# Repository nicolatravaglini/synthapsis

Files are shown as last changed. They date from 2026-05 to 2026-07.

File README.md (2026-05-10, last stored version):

# Synthapsis

## Introduzione

Synthapsis e' un sintetizzatore portatile progettato con l'intento di estrarre melodie dal chaos.
Genera note casuali seguendo un ordine stocastico definito da una matrice di Markov, modificabile in
tempo reale mediante connessioni fisiche tra pin.

## Funzionalita'

Il dispositivo è costituito da un'interfaccia a 24 nodi metallici (12 input e 12 output) tramite
i quali l'utente, utilizzando cavi con clip a coccodrillo, modella dinamicamente una catena di Markov.
Questa struttura definisce le probabilità di transizione tra le dodici note della scala cromatica:
la probabilità di passare dalla nota corrente a una delle note successive è distribuita uniformemente
tra tutti i nodi di destinazione fisicamente collegati al pin di partenza.

Per la selezione della nota successiva, al fine di evitare i pattern prevedibili tipici dei generatori
di numeri pseudo-casuali (PRNG), il software impiega un True Random Number Generator (TRNG) che sfrutta
l'hardware dell'ESP32 per estrarre entropia basata sul rumore di clock.

Dei LED disposti sotto ciascuno pin supportano la user-experience, indicando in tempo reale la nota
attualmente riprodotta mediante la loro accensione.

Le idee sulla disposizione dei pin, e conseguentemente dei LED, e' ancora da definirsi bene. Tuttavia
quella che a mio avviso sembra la piu' compatta e comoda da utilizzare e' quella di creare 2 cerchi
concentrici: su quello esterno si dispongono i pin di uscita, mentre su quello interno i pin di ingresso;
i LED sono disposti a meta' tra i due cerchi.

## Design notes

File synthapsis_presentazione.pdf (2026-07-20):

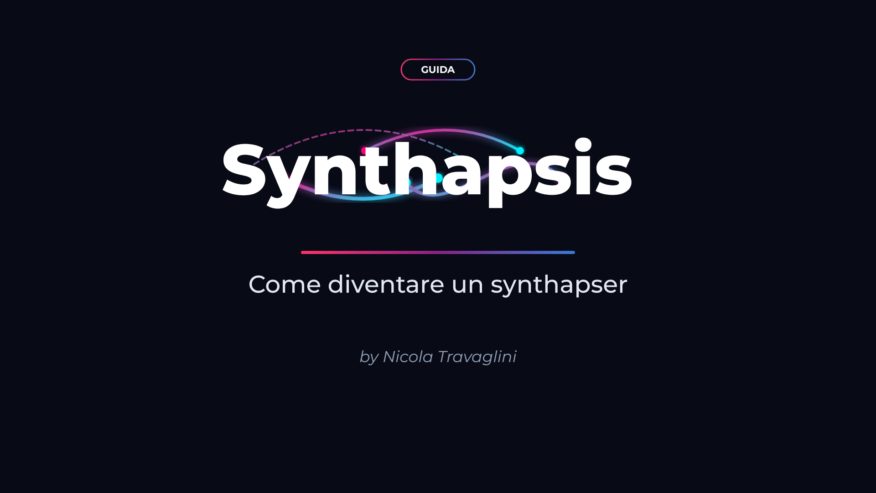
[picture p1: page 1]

GUIDA

# Synthapsis

# Come diventare un synthapser

## by Nicola Travaglini

MODALITA’

# 4 modalita’ di utilizzo

Esistono quattro principali pattern di disposizione dei collegamenti in Synthapsis.

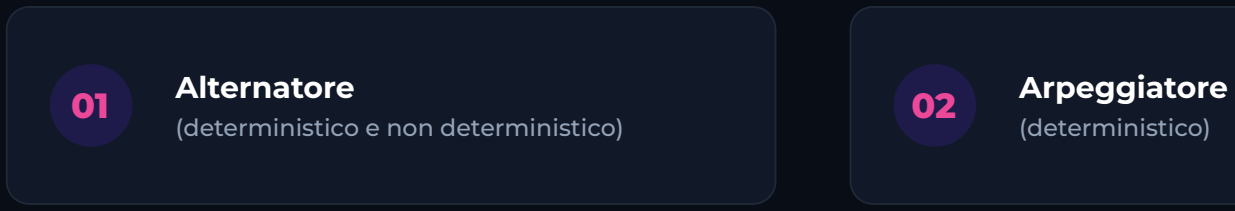
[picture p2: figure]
01 Alternatore; (deterministico e non deterministico); Arpeggiatore; (deterministico)
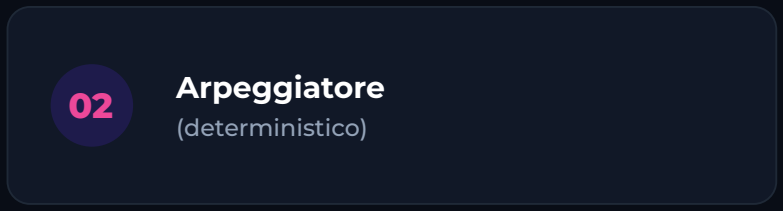
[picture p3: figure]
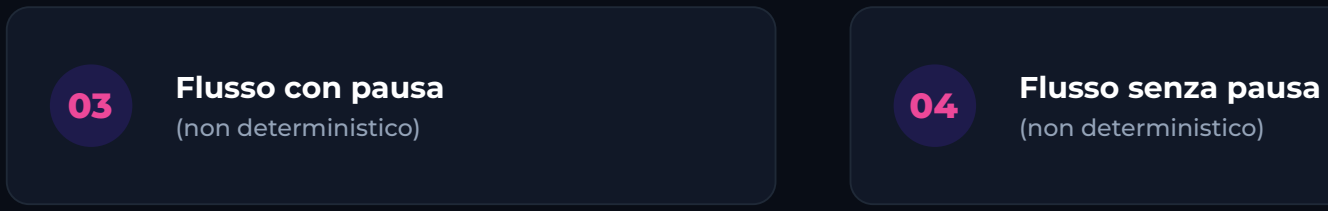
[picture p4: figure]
03 Flusso con pausa; (non deterministico); Flusso senza pausa
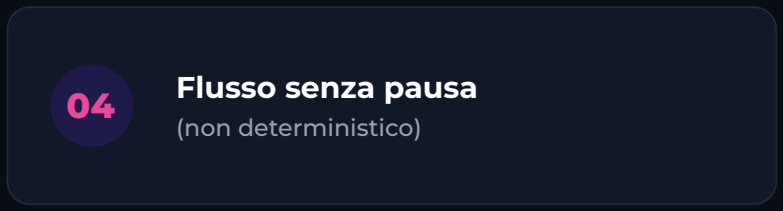
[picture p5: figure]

# Funzionamento: Alternatore

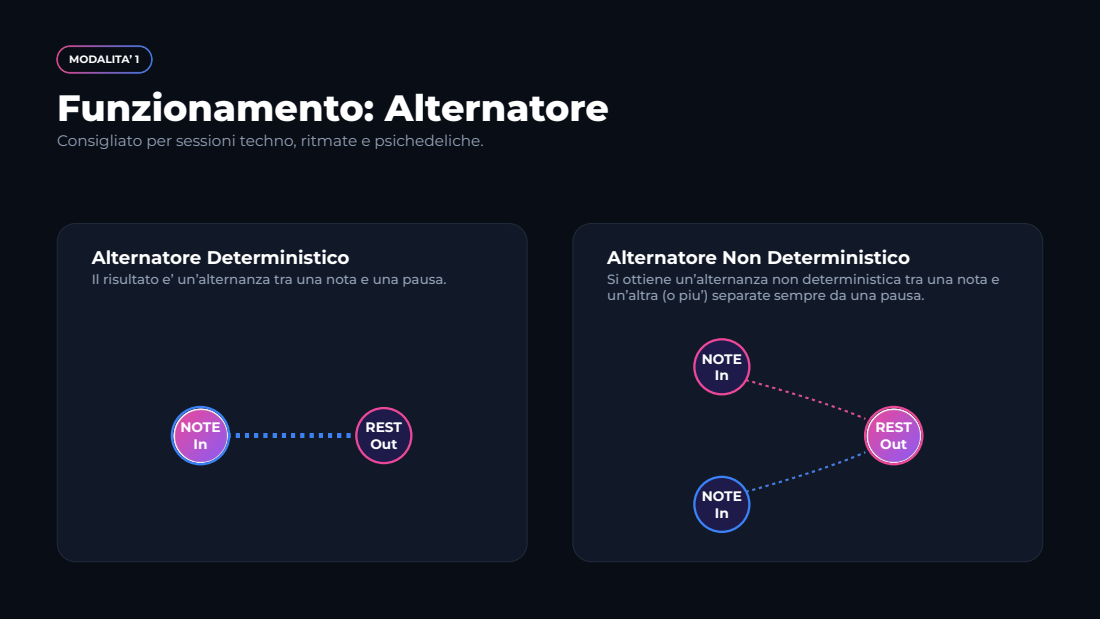
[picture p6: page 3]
MODALITA’ 1; NOTE In; REST Out

Consigliato per sessioni techno, ritmate e psichedeliche.

Alternatore Deterministico
Il risultato e’ un’alternanza tra una nota e una pausa.

Alternatore Non Deterministico
Si ottiene un’alternanza non deterministica tra una nota e
un’altra (o piu’) separate sempre da una pausa.

MODALITA’ 2

# Funzionamento: Arpeggiatore

Un semplice arpeggiatore deterministico.

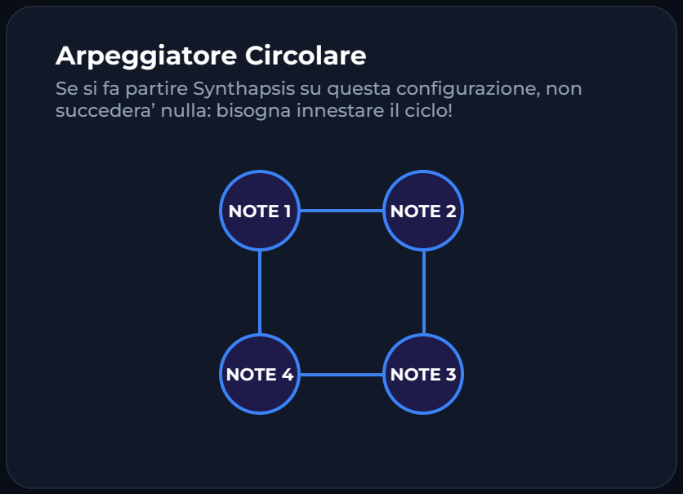
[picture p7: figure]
Arpeggiatore Circolare; NOTE 1; NOTE 2; NOTE 4; NOTE 3

Se si fa partire Synthapsis su questa configurazione, non succedera’ nulla: bisogna innestare il ciclo!

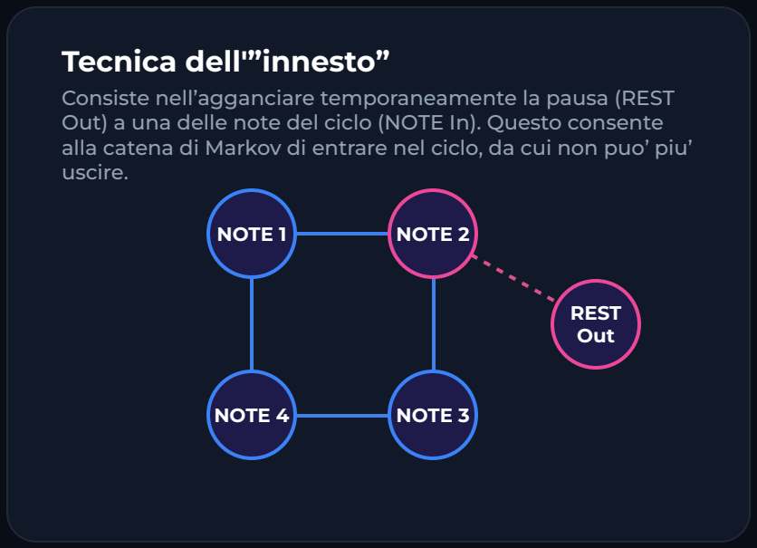
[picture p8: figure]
Tecnica dell'”innesto”; uscire.; NOTE 1; NOTE 2; NOTE 4; NOTE 3; REST Out

Consiste nell’agganciare temporaneamente la pausa (REST Out) a una delle note del ciclo (NOTE In). Questo consente alla catena di Markov di entrare nel ciclo, da cui non puo’ piu’

MODALITA’ 3

# Funzionamento: Flusso con

pausa La modalita’ piu’ generica, adatta e flessibile a ogni genere.

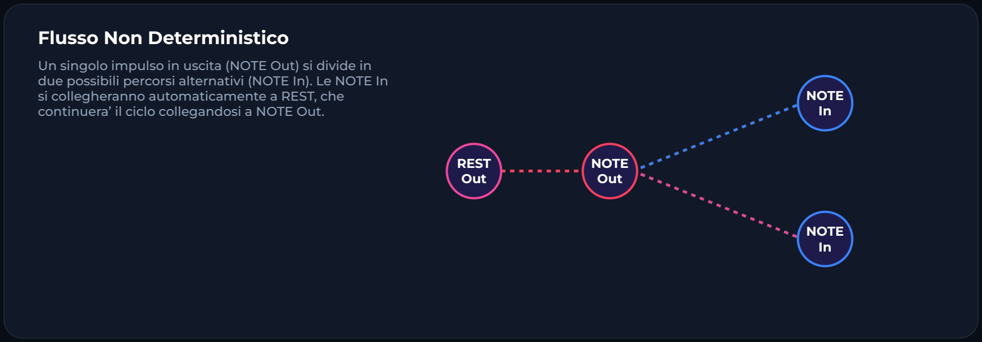
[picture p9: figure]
NOTE Out; Flusso Non Deterministico; NOTE In; REST Out

Un singolo impulso in uscita (NOTE Out) si divide in due possibili percorsi alternativi (NOTE In). Le NOTE In si collegheranno automaticamente a REST, che continuera’ il ciclo collegandosi a NOTE Out.

# Funzionamento: Flusso senza pausa

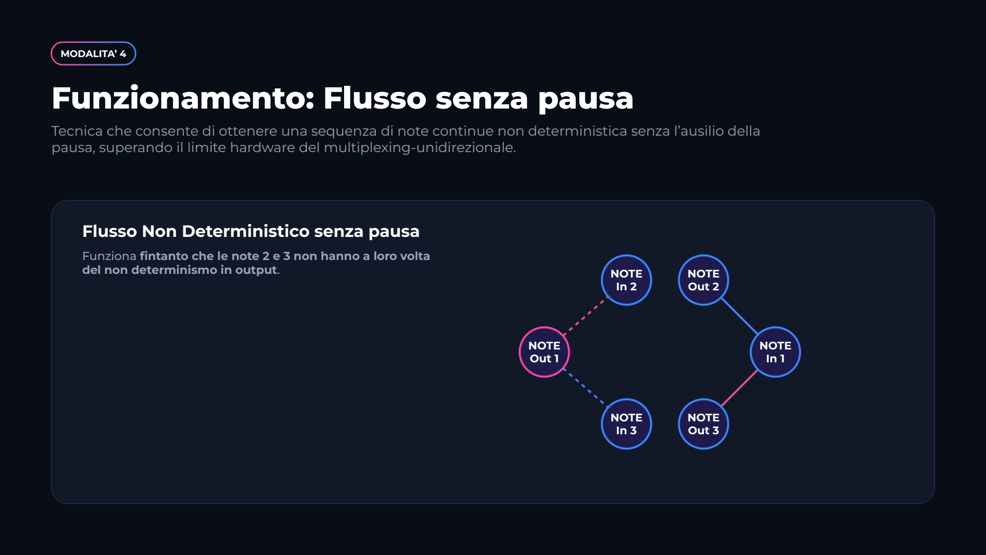
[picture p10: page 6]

MODALITA’ 4

Tecnica che consente di ottenere una sequenza di note continue non deterministica senza l’ausilio della pausa, superando il limite hardware del multiplexing-unidirezionale.

## Flusso Non Deterministico senza pausa

Funziona fintanto che le note 2 e 3 non hanno a loro volta del non determinismo in output.

NOTE
Out 1

NOTE
In 2

NOTE
Out 2

NOTE
In 3

NOTE
Out 3

NOTE
In 1

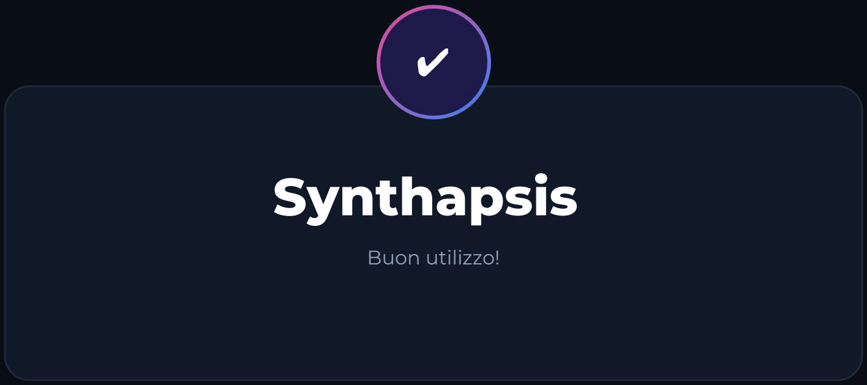
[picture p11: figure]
Synthapsis; Buon utilizzo!

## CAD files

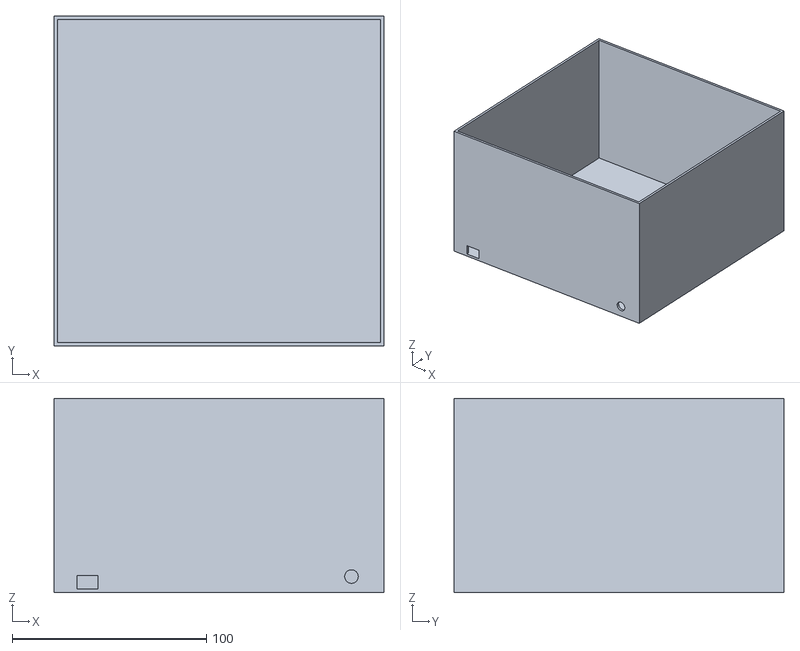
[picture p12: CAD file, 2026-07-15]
synthapsis_base.stl
170.0 x 170.0 x 100.0

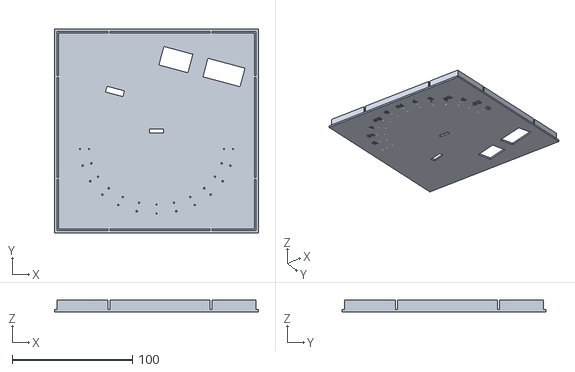
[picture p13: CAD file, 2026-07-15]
synthapsis_cover.stl
170.0 x 170.0 x 9.75

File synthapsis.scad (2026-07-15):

// Variabili di precisione
$fn = 60;

// Variabili per base
box_lunghezza = 170; 
box_larghezza = 170;
box_altezza   = 100;
parete = 1.75;
usb_l = 11;
usb_a = 7;
jack_r = 3.5;

// Variabili per cover
altezza_labbro = 8;
spessore_labbro = 1.2;
tolleranza    = 0.2;
buco_diametro = 1.31;
display_w = 12;
display_h = 3;
potent_w = 15;
potent_h = 5;
loop_btn_w = 32;
loop_btn_h = 16;
pause_btn_w = 25;
pause_btn_h = 16;
space_between = 13;

module base() {
    difference() {
        
        cube([box_lunghezza, box_larghezza, box_altezza]);

        translate([parete, parete, parete])
            cube([
                box_lunghezza - (parete * 2),
                box_larghezza - (parete * 2),
                box_altezza
            ]);

        translate([
            10 + parete,
            -1,
            parete
        ])
            cube([usb_l, parete + 2, usb_a]);

        translate([
            box_lunghezza - 15 - parete,
            -1,
            parete + jack_r + 3
        ])
            rotate([0, 90, 90])
                cylinder(h = parete + 3, r = jack_r);
    }
}

module cover() {    
    note = ["C", "C#", "D", "D#", "E", "F", "F#", "G", "G#", "A", "A#", "B", "-"];
    
    raggio_x = 60;
    raggio_y = 50;
    centro_x = box_lunghezza / 2;
    centro_y = box_altezza - raggio_y + 20;

    difference() {
        cube([box_lunghezza, box_larghezza, parete]);
        
        translate([box_lunghezza / 2 - display_w / 2, box_larghezza / 2 - display_h / 2, -1])
            cube([display_w, display_h, parete + 2]);
        
        translate([50 - potent_w/2, box_larghezza - 50 - potent_h/2, -1])
        rotate([0, 0, -15])
            cube([potent_w, potent_h, parete + 2]);
        
        
        translate([box_lunghezza - 83, box_larghezza - 30, -1])
        rotate([0, 0, -15])
            difference() {
                cube([loop_btn_w + space_between + pause_btn_w, loop_btn_h, parete + 2]);
                
                translate([pause_btn_w, 0, 0])
                    cube([space_between, loop_btn_h, parete + 2]);
            };
        
        
        for (i = [0 : 12]) {
            angolo = 180 + (i * 15);
            
            raggio_x_in = raggio_x - 3.75;
            raggio_y_in = raggio_y - 3.75;
            
            raggio_x_out = raggio_x + 3.75;
            raggio_y_out = raggio_y + 3.75;
            
            raggio_x_text = raggio_x + 10;
            raggio_y_text = raggio_y + 10;
            
            pos_x_in = centro_x + (raggio_x_in * cos(angolo));
            pos_y_in = centro_y + (raggio_y_in * sin(angolo));
            
            pos_x_out = centro_x + (raggio_x_out * cos(angolo));
            pos_y_out = centro_y + (raggio_y_out * sin(angolo));
            
            pos_x_text = centro_x + (raggio_x_text * cos(angolo));
            pos_y_text = centro_y + (raggio_y_text * sin(angolo));
            
            translate([pos_x_in, pos_y_in, -1])
                cylinder(h = parete + 2, d = buco_diametro);
            
            translate([pos_x_out, pos_y_out, -1])
                cylinder(h = parete + 2, d = buco_diametro);
            
            translate([pos_x_text, pos_y_text, -0.1])
                linear_extrude(height = 0.8)
                mirror([1, 0, 0])
                offset(r = 0.1)
                text(note[12 - i], size = 5.5, halign = "center", valign = "center", font = "Liberation Sans:style=Bold");
        }
    }

    translate([
        parete + tolleranza,
        parete + tolleranza,
        parete
    ])
    difference() {
        cube([
            box_lunghezza - (parete * 2) - (tolleranza * 2),
            box_larghezza - (parete * 2) - (tolleranza * 2),
            altezza_labbro
        ]);
        
        translate([spessore_labbro, spessore_labbro, -1])
            cube([
                box_lunghezza - (parete * 2) - (tolleranza * 2) - (spessore_labbro * 2),
                box_larghezza - (parete * 2) - (tolleranza * 2) - (spessore_labbro * 2),
                altezza_labbro + 2
            ]);
        
        translate([-5, box_larghezza / 4, -1])
            cube([box_lunghezza + 10, 2, altezza_labbro + 2]);
        translate([-5, (box_larghezza / 4) * 3, -1])
            cube([box_lunghezza + 10, 2, altezza_labbro + 2]);
        
        translate([box_lunghezza / 4, -5, -1])
            cube([2, box_larghezza + 10, altezza_labbro + 2]);
        translate([(box_lunghezza / 4) * 3, -5, -1])
            cube([2, box_larghezza + 10, altezza_labbro + 2]);
    }
}

// Decommentare prima base() e poi cover()
// base();
// cover();

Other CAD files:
synthapsis_v1.scad

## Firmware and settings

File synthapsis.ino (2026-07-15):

#include <MozziGuts.h>
#include <Oscil.h>
#include <tables/sin2048_int8.h>
#include <tables/saw2048_int8.h>
#include <tables/triangle2048_int8.h>
#include <EventDelay.h>
#include <ADSR.h>
#include <AudioDelay.h>
#include <LowPassFilter.h>
#include <Wire.h>
#include <Adafruit_GFX.h>
#include <Adafruit_SSD1306.h>
#include <Adafruit_MCP23X17.h>

class Button {
  private:
    int pin;
    bool lastButtonState;

  public:
    Button(int pin) {
      this->pin = pin;
      this->lastButtonState = LOW;
    }

    void begin() {
      pinMode(pin, INPUT_PULLDOWN);
    }

    bool update() {
      bool currentButtonState = digitalRead(pin);
      bool wasPressed = (currentButtonState == HIGH && this->lastButtonState == LOW);
      this->lastButtonState = currentButtonState;
      return wasPressed;
    }
};

// Hardware
const int BPM_POT_PIN = 34;
const int LOOP_LED_PIN = 33;
const int LOOP_BTN_PIN = 32;
const int PAUSE_BTN_PIN = 4;
const int I2C_SDA_PIN = 21;
const int I2C_SCL_PIN = 22;

const int DISPLAY_WIDTH = 128;
const int DISPLAY_HEIGHT = 64;

const int DISPLAY_ADDR = 0x3C;
const int MCP1_ADDR = 0x27;
const int MCP2_ADDR = 0x26;

// Mutex
portMUX_TYPE matrixMux = portMUX_INITIALIZER_UNLOCKED;

// Consts
enum Note {
  DO,
  DO_SHARP,
  RE,
  RE_SHARP,
  MI,
  FA,
  FA_SHARP,
  SOL,
  SOL_SHARP,
  LA,
  LA_SHARP,
  SI,
  REST,

  NUM_NOTES
};
const int NOTES_FREQ[] = {262, 277, 294, 311, 330, 349, 370, 392, 415, 440, 466, 494, 0};
Oscil <SIN2048_NUM_CELLS, AUDIO_RATE> aSin(SIN2048_DATA);
// Oscil <SAW2048_NUM_CELLS, AUDIO_RATE> aSin(SAW2048_DATA);
// Oscil <TRIANGLE2048_NUM_CELLS, AUDIO_RATE> aSin(TRIANGLE2048_DATA);
const int UPDATE_CONTROL_FREQ = 64;
const int MIN_BPM = 50;
const int MAX_BPM = 210;
const int BAR_LENGTH = 16;

// Effects
EventDelay noteDuration;
ADSR <UPDATE_CONTROL_FREQ, AUDIO_RATE> envelope;
AudioDelay<16384, int> aDelay; 
LowPassFilter lpf;
int reverbLevel;

// Vars
Note currentNote;
float markovMatrix[NUM_NOTES][NUM_NOTES];
int bpm;
float volume;
bool isLoop;
bool triggeredLoop;
bool isPause;
Note barNotes[BAR_LENGTH];
int barIndex;
Button loopBtn(LOOP_BTN_PIN);
Button pauseBtn(PAUSE_BTN_PIN);
Adafruit_SSD1306 display(DISPLAY_WIDTH, DISPLAY_HEIGHT, &Wire, -1);
Adafruit_MCP23X17 mcp1;
Adafruit_MCP23X17 mcp2;

int lastBpm = -1;
bool lastPause = false;
int lastBarIndex = -1;

void nextNote() {
  float randomNumber = (float) esp_random() / (float) UINT32_MAX;
  // Get random note using CDF
  float sum = 0;
  for (int i=0; i<NUM_NOTES; i++) {
    sum += markovMatrix[currentNote][i];
    if (sum >= randomNumber || i == NUM_NOTES - 1) {
      currentNote = (Note)i;
      break;
    }
  }
}

void playCurrentNote() {
  if (currentNote != REST) {
    aSin.setFreq(NOTES_FREQ[currentNote]);
    envelope.noteOn();
  } else {
    envelope.noteOff();
  }
}

void setBpm() {
  int bpmPotValue = analogRead(BPM_POT_PIN);
  bpm = map(bpmPotValue, 0, 4095, MAX_BPM, MIN_BPM);
  if (bpm == MAX_BPM) bpm = 1000;
  noteDuration.set(60000 / bpm);
}

const char* getNoteString(Note note) {
  switch (note) {
    case DO: return "C";
    case DO_SHARP: return "C#";
    case RE: return "D";
    case RE_SHARP: return "D#";
    case MI: return "E";
    case FA: return "F";
    case FA_SHARP: return "F#";
    case SOL: return "G";
    case SOL_SHARP: return "G#";
    case LA: return "A";
    case LA_SHARP: return "A#";
    case SI: return "B";
    case REST: return "-";
    default: return "";
  }
}

void displayCurrentNote() {
  const char* noteText = getNoteString(currentNote);
  display.setTextSize(2);
  display.setTextColor(WHITE);

  int16_t x1, y1;
  uint16_t w, h;
  display.getTextBounds(noteText, 0, 0, &x1, &y1, &w, &h);
  
  int16_t x = (DISPLAY_WIDTH - w) / 2;
  int16_t y = (DISPLAY_HEIGHT - h) / 2;
  
  display.setCursor(x, y);
  display.print(noteText);
}

void displayIsLoop() {
  display.setTextSize(1);
  if (!isLoop) display.setTextColor(WHITE);
  else display.setTextColor(BLACK, WHITE);
  display.setCursor(0, 0);
  display.print(" L ");
}

void displayIsPause() {
  if (isPause) {
    display.setTextSize(1);
    display.setTextColor(WHITE);
    display.setCursor(DISPLAY_WIDTH - 3 * 6, 0);
    display.print(" P ");
  }
}

void displayBpm() {
  display.setTextSize(1);
  display.setTextColor(WHITE);
  int digits = (int)log10(bpm) + 1;
  int textWidth = (5 + digits) * 6;
  int x = DISPLAY_WIDTH - textWidth - 2;
  display.setCursor(x, 54);
  display.print("BPM: ");
  display.print(bpm);
}

void displayBarIndex() {
  display.setTextSize(1);
  display.setTextColor(WHITE);
  int digits = ((int)log10(barIndex+1) + 1) + ((int)log10(BAR_LENGTH) + 1);
  int textWidth = (1 + digits) * 6;
  display.setCursor(2, 54); 
  display.print(barIndex+1);
  display.print("/");
  display.print(BAR_LENGTH);
}

void updateDisplay() {
  display.clearDisplay();
  displayCurrentNote();
  displayIsLoop();
  displayIsPause();
  displayBpm();
  displayBarIndex();
  display.display();
}

void updateMarkovMatrix() {
  float tmpMatrix[NUM_NOTES][NUM_NOTES];

  for (int i=0; i<NUM_NOTES; i++) {
    mcp1.pinMode(i, OUTPUT);
    mcp1.digitalWrite(i, LOW);

    uint16_t mcp2States = mcp2.readGPIOAB();
    int counter = 0;

    for (int j=0; j<NUM_NOTES; j++) {
      int linked = ((~mcp2States) >> j) & 0x01;
      tmpMatrix[i][j] = linked;
      counter += linked;
    }

    // Normalize
    if (counter > 0) {
      float invCounter = 1.0 / (float)counter;
      for (int j=0; j<NUM_NOTES; j++) tmpMatrix[i][j] *= invCounter;
    } else {
      // Fallback to REST if nothing is connected
      tmpMatrix[i][REST] = 1;
    }

    mcp1.pinMode(i, INPUT);
  }

  // Update the real Markov matrix
  portENTER_CRITICAL(&matrixMux);
  for(int i=0; i<NUM_NOTES; i++) {
    for(int j=0; j<NUM_NOTES; j++) {
      markovMatrix[i][j] = tmpMatrix[i][j];
    }
  }
  portEXIT_CRITICAL(&matrixMux);
}

void hardwareUpdateTask(void* pvParameters) {
  while (true) {
    updateMarkovMatrix();
    setBpm();
    if (bpm != lastBpm || isPause != lastPause || barIndex != lastBarIndex) {
      updateDisplay();
      lastBpm = bpm;
      lastPause = isPause;
      lastBarIndex = barIndex;
    }
    vTaskDelay(pdMS_TO_TICKS(100));
  }
}

void setup() {
  // Env begins
  Wire.begin(I2C_SDA_PIN, I2C_SCL_PIN);
  Wire.setClock(400000);
  Serial.begin(115200);

  // Init loop led and button
  pinMode(LOOP_LED_PIN, OUTPUT);
  loopBtn.begin();

  // Init display
  if (!display.begin(SSD1306_SWITCHCAPVCC, DISPLAY_ADDR)) {
    Serial.println(F("SSD1306 initialization failed"));
    while (1);
  }
  display.clearDisplay();

  // Init MCPs
  if (!mcp1.begin_I2C(MCP1_ADDR)) {
    Serial.println("MCP1 initialization failed");
    while (1);
  }

  if (!mcp2.begin_I2C(MCP2_ADDR)) {
    Serial.println("MCP2 initialization failed");
    while (1);
  }

  for (int i=0; i<NUM_NOTES; i++) {
    mcp1.pinMode(i, INPUT);
    mcp2.pinMode(i, INPUT_PULLUP);
  }
  
  // Init vars
  currentNote = REST;
  bpm = 100;
  volume = 1;
  isLoop = false;
  triggeredLoop = false;
  isPause = true;
  for (int i=0; i<BAR_LENGTH; i++) barNotes[i] = REST;
  barIndex = 0;
  reverbLevel = 255; // 0-255

  // Init Markov matrix
  for (int i=0; i<NUM_NOTES; i++) {
    for (int j=0; j<NUM_NOTES; j++) {
      markovMatrix[i][j] = 0.0;
    }
  }

  // Init envelope
  envelope.setADLevels(255, 127);
  envelope.setTimes(20, 100, 10000, 200);
  lpf.setCutoffFreq(100);
  lpf.setResonance(0);

  // Start task on core 0
  xTaskCreatePinnedToCore(hardwareUpdateTask, "HW_Task", 10000, NULL, 1, NULL, 0);
  
  // Start Mozzi
  startMozzi(UPDATE_CONTROL_FREQ);

  noteDuration.start();
  playCurrentNote();
}

void updateControl() {
  if (loopBtn.update()) {
    triggeredLoop = !triggeredLoop;
  }

  if (pauseBtn.update()) {
    isPause = !isPause;
    barIndex = 0;
  }

  digitalWrite(LOOP_LED_PIN, isLoop);

  if (noteDuration.ready() && !isPause) {
    barIndex = (barIndex + 1) % BAR_LENGTH;

    if (triggeredLoop && barIndex == 0) {
      isLoop = !isLoop;
      triggeredLoop = false;
    } else if (triggeredLoop) {
      digitalWrite(LOOP_LED_PIN, !isLoop);
    }

    if (!isLoop) {
      portENTER_CRITICAL(&matrixMux);
      nextNote();
      portEXIT_CRITICAL(&matrixMux);

      barNotes[barIndex] = currentNote;
    } else {
      currentNote = barNotes[barIndex];
    }
    
    playCurrentNote();
    noteDuration.start();
  }

  envelope.update();
}

int updateAudio() {
  // Get signal of note
  int envValue = envelope.next(); 
  int asig = (aSin.next() * envValue) >> 8;
  asig = (int)(asig * volume);

  if (isPause) {
    asig = 0;
  }

  static int feedback = 0;
  
  // Calculate delay
  int delayInput = (asig >> 2) + feedback; 
  int delayedSignal = aDelay.next(delayInput, 8192);
  int filteredEcho = lpf.next(delayedSignal);
  
  // Calculate new feedback
  feedback = (filteredEcho * 15) >> 4;

  // Calculate reverb
  int rawWet = filteredEcho >> 2;
  int inverseEnv = 255 - envValue;
  int duckedReverb = (rawWet * inverseEnv) >> 8;
  duckedReverb = (duckedReverb * reverbLevel) >> 8;

  // Add reverb & delay to signal, and return
  return asig + duckedReverb;
}

void loop() {
  audioHook();
}

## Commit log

2026-05-19 feat: loop led and button
2026-06-13 pause button
2026-07-14 openscad model
    [synthapsis_v1.scad]
2026-07-15 openscad and stl update
    [synthapsis.scad, synthapsis_base.stl, synthapsis_cover.stl]
